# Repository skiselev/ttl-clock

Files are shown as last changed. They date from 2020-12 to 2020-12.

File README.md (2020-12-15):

# TTL Clock
74xx ICs Based Digital Clock

## Introduction
I got a bit tired from soldering SMD components, writing firmware, (and also observing people building vintage-looking Nixie clocks using modern microcontrollers). And recently when cleaning my parts boxes I found several 74LS47 7-segment decoders, some 74LS90 decade counters, and MAN1A 7-segment displays. So I thought, why not to build a nice little clock using these components.

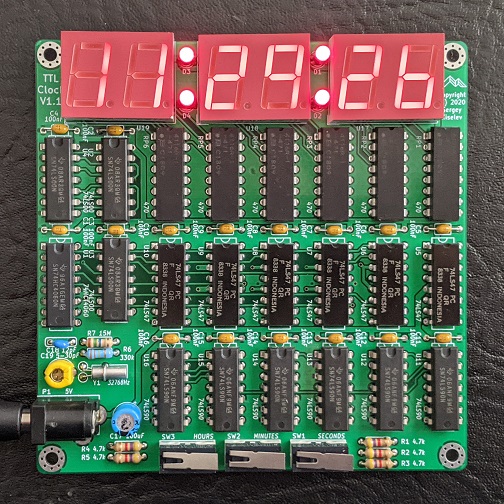
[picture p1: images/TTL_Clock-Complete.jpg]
Assembled Clock Board


## Assembly Instructions

[Assembly Instructions](Assembly_Instructions.md)

## Design Overview
Please refer to the schematic file in the Design Files section below.

The clock uses a 32768 Hz quartz crystal (X1) and 74HC4060 counter/divider IC (U1) to generate 2 Hz signal. This signal is divided further by 2 using a part of 74LS90 counter (U6). The obtained 1 Hz signal is fed to two 74LS90 counters (U11 and U12) that count seconds. The seconds reset circuit implemented using two 74LS00 NAND gates (U4A and U4B). This circuit resets both seconds and tens of seconds counters when they reach "60" or when "SECONDS" switch (SW1) is pressed, allowing seconds adjustment.

The most significant bit of tens of seconds counter is fed to the minutes counter implemented using two 74LS90 counters (U13 and U14) through a multiplexer built from three 74LS00 NAND gates (U2C, U2D, U4D). The multiplexer selects between this "one pulse per minute" signal and the 2 Hz signal allowing setting up minutes. Two additional 74LS00 NAND gates (U2A and U2B) implement an RS flip-flop used to de-bounce "MINUTES" switch (SW2). The tens of the minutes 74LS90 counter (U14) is wired so that it resets itself when it reaches count of "6", so that minutes wrap around at "60".

Similarly to minutes, the most significant bit of tens of minutes is fed to the hours counter implemented using two 74LS90 counters (U15 and U16) through a multiplexer built from three 74LS00 NAND gates (U3C, U3D, U4C). The multiplexer selects between this "one pulse per hour" signal and the 2 Hz signal allowing setting up hours. Two additional 74LS00 NAND gates (U3A and U3B) implement an RS flip-flop used to de-bounce "HOURS" switch (SW3). Both hours counters are wired in such a way that they will reset themselves once they reach the count of "24".

Six 74LS47 7-segment decoders (U5 - U10) are used to decode the binary outputs of the counters and 7-segment displays (U17 - U19) display the result in human readable 24-hours time format.

## Design Files

[Schematic - Version 1.1](KiCad/TTL_Clock-Schematic-1.1.pdf)

[Board - Version 1.1](KiCad/TTL_Clock-Board-1.1.pdf)

## Bill of Materials

[TTL Clock V1.1 project on Mouser.com](https://www.mouser.com/ProjectManager/ProjectDetail.aspx?AccessID=75baf81884) - View and order all components except of the PCB.

[TTL Clock Version 1.1 project on OSH Park](https://oshpark.com/shared_projects/GOxwvQh1) - Order PCBs.

Component type     | Reference | Description                                 | Quantity | Possible sources and notes
------------------ | --------- | ------------------------------------------- | -------- | --------------------------
PCB                |           | TTL Clock V1.1 Printed Circuit Board        | 1        | Order from [OSH Park](https://oshpark.com/shared_projects/GOxwvQh1) or another PCB manufacturer using provided KiCad or Gerber files
Stand              |           | 3D printed stand for the clock              | 1        | (Optional) Print on a 3D printer using [stand.stl](printed_parts/stand.stl). Thanks to Michael K. for designing this stand.
Screw              |           | M3 x 6mm screw                              | 2        | (Optional)
Capacitor          | C1 - C16  | 0.1uF, 50V, multilayer ceramic capacitor, axial | 16   | Mouser: [594-A104K15X7RF5UAA](https://www.mouser.com/ProductDetail/594-A104K15X7RF5UAA)
Capacitor          | C17       | 100uF, 25V, electrolytic capacitor, radial, 6.3 mm diameter | 1 | Mouser: [710-860040473003](https://www.mouser.com/ProductDetail/710-860040473003)
Capacitor          | C18       | 12pF, 50V, multilayer ceramic capacitor, 5.08 mm lead spacing | 1 | Mouser: [810-FK28C0G1H120J](https://www.mouser.com/ProductDetail/810-FK28C0G1H120J)
Trimmer Capacitor  | C19       | 5-30pF, trimmer capacitor, 5 mm lead spacing | 1       | Mouser: [659-GKG20015](https://www.mouser.com/ProductDetail/659-GKG20015)
LED                | D1 - D4   | 3 mm LED, same color as U17 - U19            | 4       | Mouser: [859-LTL-4221](https://www.mouser.com/ProductDetail/859-LTL-4221) (red, 623 nm) [859-LTL-4211](https://www.mouser.com/ProductDetail/859-LTL-4211) (red, 697 nm, 2.5 mcd), [859-LTL-4231](https://www.mouser.com/ProductDetail/859-LTL-4231) (green, 565 nm)
Connector          | P1        | DC Power Jack                               | 1        | Mouser: [806-KLDX-0202-A](https://www.mouser.com/ProductDetail/806-KLDX-0202-A)
Resistor           | R1 - R5   | 4.7 kOhm, 1/4 W                             | 5        | Mouser: [588-OK4725E-R52](https://www.mouser.com/ProductDetail/588-OK4725E-R52), [603-MFR25SFRF52-4K7](https://www.mouser.com/ProductDetail/603-MFR25SFRF52-4K7)
Resistor           | R6        | 330 kOhm, 1/4 W                             | 1        | Mouser: [588-OK3345E-R52](https://www.mouser.com/ProductDetail/588-OK3345E-R52)
Resistor           | R7        | 15 MOhm, 1/4 W                              | 1        | Mouser: [660-CF1/4C156J](https://www.mouser.com/ProductDetail/660-CF1-4C156J)
Resistor Array     | RR1 - RR6 | 470 Ohm, 8 isolated resistors, 16 pin DIP   | 6        | Mouser: [652-4116R-1LF-470](https://www.mouser.com/ProductDetail/652-4116R-1LF-470), [652-4116R-1-470](https://www.mouser.com/ProductDetail/652-4116R-1-470), or 46 x 470 ohm discrete resistors
Switch             | SW1 - SW3 | SPDT momentary switch, Omron D2F            | 3        | Mouser: [612-SS0750301F040P1A](https://www.mouser.com/ProductDetail/612-SS0750301F040P1A), [653-D2F-01L](https://www.mouser.com/ProductDetail/653-D2F-01L)
Integrated Circuit | U1        | 14-stage binary counter with oscillator, 74HC4060 | 1  | Mouser: [595-SN74HC4060N](https://www.mouser.com/ProductDetail/595-SN74HC4060N), [595-CD74HCT4060E](https://www.mouser.com/ProductDetail/595-CD74HCT4060E), [595-CD74HC4060E](https://www.mouser.com/ProductDetail/595-CD74HC4060E)
Integrated Circuit | U2 - U4   | Quad 4-input NAND gate, 74LS00              | 3        | Mouser: [595-SN74LS00N](https://www.mouser.com/ProductDetail/595-SN74LS00N), [595-SN74LS00NE4](https://www.mouser.com/ProductDetail/595-SN74LS00NE4)
Integrated Circuit | U5 - U10  | BCD to 7-segment decoder, 74LS47 or 74LS247 | 6        | Mouser: [595-SN74LS47N](https://www.mouser.com/ProductDetail/595-SN74LS47N), [595-SN74LS47NE4](https://www.mouser.com/ProductDetail/SN74LS47NE4), [595-SN74LS247N](https://www.mouser.com/ProductDetail/595-SN74LS247N), [595-SN74LS247NE4](https://www.mouser.com/ProductDetail/595-SN74LS247NE4)
Integrated Circuit | U11 - U16 | Decade counter, 74LS90                      | 6        | Mouser: [595-SN74LS90N](https://www.mouser.com/ProductDetail/595-SN74LS90N), [595-SN74LS90NE4](https://www.mouser.com/ProductDetail/595-SN74LS90NE4)
LED Display        | U17 - U19 | 7-segment LED display, 2 digits, common anode | 3      | Mouser: [859-LTD-6910HR](https://www.mouser.com/ProductDetail/859-LTD-6910HR) (red, 623 nm), [859-LTD-6410G](https://www.mouser.com/ProductDetail/859-LTD-6410G) (green, 569 nm)
Crystal Resonator  | X1        | 32768 Hz, 12.5pF load capacitance, tuning fork | 1     | Mouser: [695-CFS-20632768EZBB](https://www.mouser.com/ProductDetail/695-CFS-20632768EZBB), [815-AB26T-32.768KHZ](https://www.mouser.com/ProductDetail/815-AB26T-32.768KHZ)
Power Supply       |           | 5 V, 550 mA                                 | 1        | Mouser: [490-SWI3-5-N-P5](https://www.mouser.com/ProductDetail/490-SWI3-5-N-P5) (US plug), [490-SWI3-5-E-P5](https://www.mouser.com/ProductDetail/490-SWI3-5-E-P5) (EU plug)

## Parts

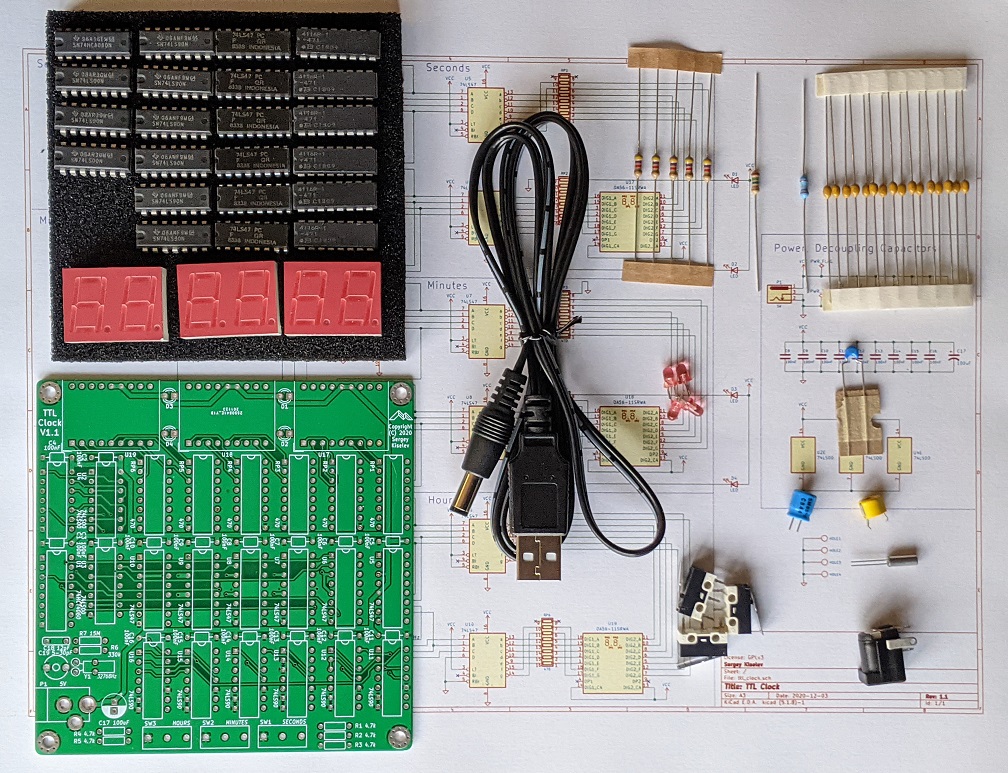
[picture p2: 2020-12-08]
images/TTL_Clock-Kit_Parts_Large.jpg

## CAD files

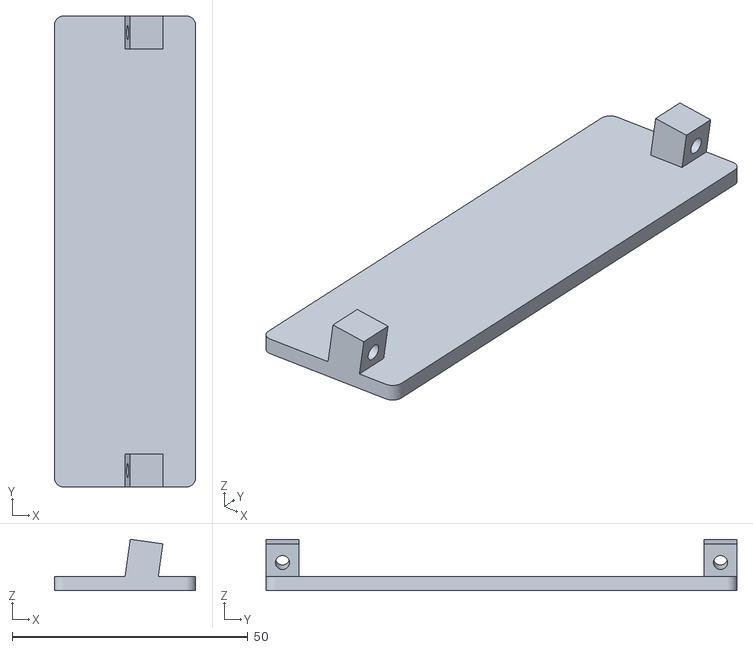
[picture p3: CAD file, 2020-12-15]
printed_parts/stand.stl
30.0 x 100.0 x 10.9

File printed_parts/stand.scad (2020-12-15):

// TTL Clock Stand
//
// This program is free software: you can redistribute it and/or modify
// it under the terms of the GNU General Public License as published by
// the Free Software Foundation, either version 3 of the License, or
// (at your option) any later version.
//
// This program is distributed in the hope that it will be useful,
// but WITHOUT ANY WARRANTY; without even the implied warranty of
// MERCHANTABILITY or FITNESS FOR A PARTICULAR PURPOSE.  See the
// GNU General Public License for more details.
//
// You should have received a copy of the GNU General Public License
// along with this program.  If not, see <https://www.gnu.org/licenses/>.

corner_radius = 2;
$fn = 60;
width=100;
depth=30;
thick=3;
standoff_width=7;
standoff_depth=7;
standoff_height=8;
standoff_angle=8;
hole_diameter=3;

render_stand();

module render_stand() {
    // base plate
    rounded_box(depth,width,thick);
    // standoff 1
    translate([depth/2,0,thick]) {
        standoff(standoff_depth,standoff_width,standoff_height,hole_diameter,standoff_angle);
    }
    // standoff 2
    translate([depth/2,width-standoff_width,thick]) {
        standoff(standoff_depth,standoff_width,standoff_height,hole_diameter,standoff_angle);
    }
}

////////////////////////////////////////////////////////////////////////////////
module standoff(d,w,h,hole,angle)
{
    rotate([0,angle,0]) {
        difference () {
            cube([d,w,h]);
            translate([d/2,w/2,h/2]) {
                rotate([0,90,0]) {
                    cylinder(d=hole,h=d+0.2,center=true);
                }
            }
        }
    }
}

////////////////////////////////////////////////////////////////////////////////
// Rounded Box
module rounded_box(w,l,h,cr=corner_radius)
{
    translate([cr,cr,0]) {
        minkowski() {
            cube([w-cr*2,l-cr*2,h/2]);
            cylinder(r=cr,h=h/2,center=false);
        }
    }
}

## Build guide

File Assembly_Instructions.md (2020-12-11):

# TTL Clock - Assembly Instructions

## Introduction
TTL Clock is a medium complexity project. While it uses through-hole components only, and therefore requires only basic soldering skills, it contains quite a few components.

## Prerequisites

### Tools and Supplies

* Soldering iron or soldering station
* Needle nose pliers
* Cutters
* Well lit and ventilated workspace
* Solder
* Small Phillips screwdriver (optional)
* Multimeter (optional)
* ESD safe surface and ESD strap (optional)
* Isopropyl alcohol and a wipe to clean the flux (optional)

### Parts

* TTL Clock parts as described in [Bill of Materials](https://github.com/skiselev/ttl-clock#bill-of-materials)
* USB power supply, or 5V DC power supply with 2.1 mm internal diameter / 5.5 mm external diameter plug

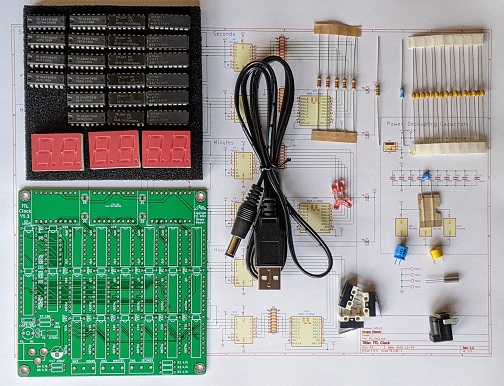
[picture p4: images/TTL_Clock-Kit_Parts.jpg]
TTL Clock kit parts


## Assembly Steps

1. Gather supplies and parts
  * Check that you have all the equipment and parts listed in the [Prerequisites](prerequisites) section above
  * Organize your workspace. If available, use ESD-safe surface and ESD strap when working on this project
2. Assemble the components going from lower profile components to higher profile components. Here is the recommended order:
  * Form the leads of 100 nF capacitors as shown on the photo below. Using needle nose pliers, hold the capacitor by the lead close to the capacitor's package, and then bend the lead using your fingers. The distance between bent leads should be 7.62 mm (0.3")

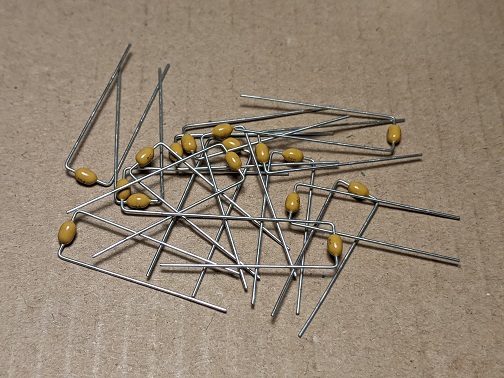
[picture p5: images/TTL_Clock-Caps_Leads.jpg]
Formed capacitor leads

  * Solder capacitors C1 - C16. Note that these are non-polarized ceramic capacitors, so they can be oriented either way. Trim the leads using cutters

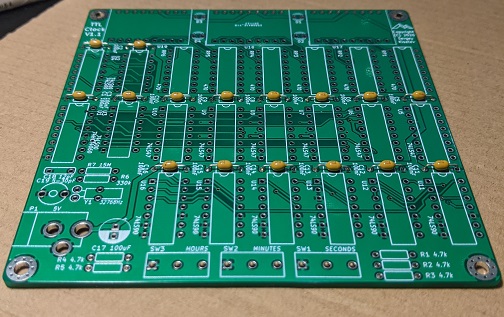
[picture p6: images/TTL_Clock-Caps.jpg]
Board with soldered capacitors

  * Form the leads of the resistors. Using your fingers bend the leads down as close to the resistor's package as possible. The distance between bent leads should be 7.62 mm (0.3")

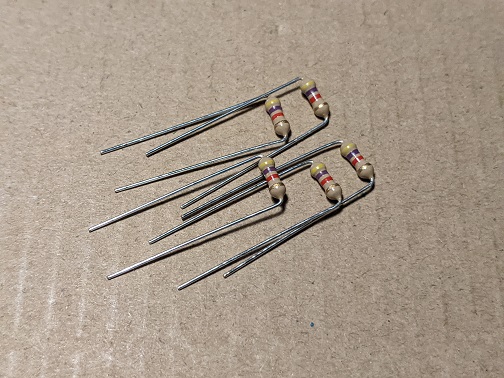
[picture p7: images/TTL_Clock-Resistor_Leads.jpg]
Formed resistor leads

  * Solder 4.7 kohm resistors R1 - R5. These resistors are marked with yellow-purple-red-gold color code. The resistors are not polarized and can be oriented either way. Trim the leads using cutters
  * Solder 330 kohm resistor R6. This resistor is marked with orange-orange-yellow-gold color code. Trim the leads using cutters
  * Solder 15 Mohm resistor R7. This resistor is marked with brown-green-blue-golden color code. Trim the leads using cutters

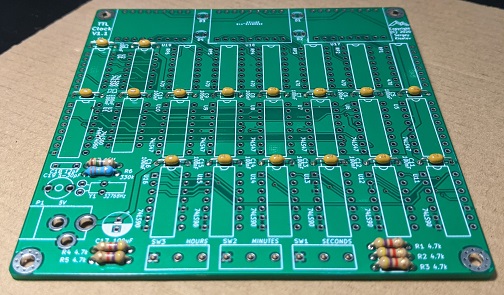
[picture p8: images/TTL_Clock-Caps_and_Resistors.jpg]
Board with soldered resistors and capacitors

  * Form the leads of the crystal oscillator X1. Hold it by the leads with needle nose pliers as close to the package as possible, when gently bend the leads down
  * Solder crystal oscillator. Trim the leads using cutters
  * Using one of the cut resistor leads and needle nose pliers, form a U-shaped bracket to hold the crystal oscillator as shown on the photo below

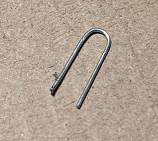
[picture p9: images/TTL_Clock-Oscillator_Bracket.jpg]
Oscillator bracket

  * Solder the crystal oscillator bracket. Make sure that it securely holds the crystal oscillator

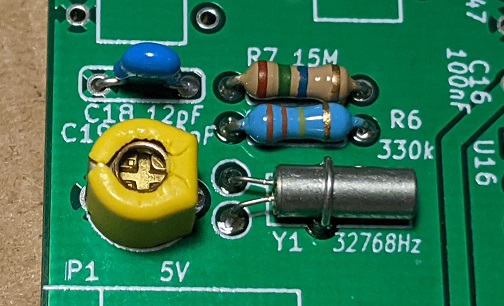
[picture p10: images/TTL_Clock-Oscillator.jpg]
Oscillator area

  * Solder U1 - U16 integrated circuits as follows:
    * Prior to placing an integrated circuit on the board, bend its leads slightly, so they point 90 degrees downward. Put the IC on the side and gently push it down to bend the leads. Repeat on the other side of the IC
    * Double check that you're placing the integrated circuit in the right spot on the board, check the IC orientation. The index notch on the IC should match the boards silkscreen
    * Solder two opposite pins (for example, pin 1 and pin 9). Flip the board to the component side and __check the IC orientation and position again!__ It is not too late to desolder the IC and fix the mistake.
    * Solder remaining pins quickly (3 seconds per pin), to avoid overheating the integrated circuit
  * Solder RR1 - RR6 resistor arrays. Follow integrated circuits instructions in the previous step
  * Solder C18 capacitor. This is a non-polarized ceramic capacitor, so it can be oriented either way
  * Solder C19 trimmer capacitor. This is a non-polarized capacitor, so it can be oriented either way

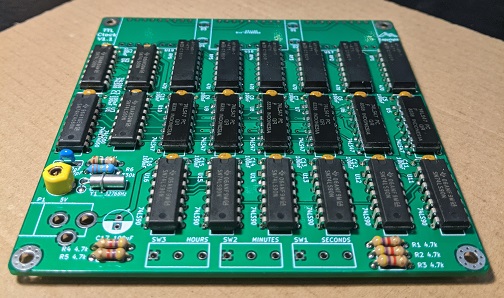
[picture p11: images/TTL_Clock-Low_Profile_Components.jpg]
Board with low profile components

  * Solder C17 capacitor. Note that this is a __polarized__ electrolytic capacitor and it needs to be oriented properly. Make sure that the negative lead of the capacitor (marked on the package) matches the white colored area on the PCB.
  * Solder LEDs D1 - D4
    * Note that the LEDs are __polarized__. The square pads on the board correspond to the negative (cathode) lead of the LED. The negative leads on the LED usually marked by an indent on otherwise round LED package, or by a shorter lead. The LEDs included in the kit will have their positive leads colored red. If in doubt - use the multimeter (set to diode mode) to check the polarity
    * When soldering LEDs, it is recommended to leave some space between the LED packages and the board and to keep soldering time to minimal to avoid overheating the LED
  * Solder LED displays U17 - U19
    * LED displays are __polarized__. Make sure that they are oriented correctly prior to soldering. The proper orientation can be easily determined by looking at the decimal point on the displays. It should reside on the bottom side on the display (close to the resistor arrays)
    * As with LEDs and integrated circuits, avoid overheating the displays
  * Solder DC power jack P1 
  * Solder SW1 - SW3 switches. Note that switches should be __oriented__ so that the pin 1 is on the left side. Pin 1 is the pin closest to the place where the hinge attaches to the switch. Refer to the picture below
 
Complete board

3. Double check your work. Make sure that all components and all leads are well soldered
4. If desired, clean the flux residue using wipes or q-tips soaked in isopropyl alcohol. Let the board dry before testing
5. Power on the board. It should work right away!
6. Set the time using the buttons
  * Reset seconds first
  * Set minutes next
  * Finally set hours
7. If needed fine tune the clock by turning the trim capacitor using a smallscrew driver. You might want to let the clock run overnight to check if gains or loses time

__Congratulations! Enjoy your TTL Clock!__

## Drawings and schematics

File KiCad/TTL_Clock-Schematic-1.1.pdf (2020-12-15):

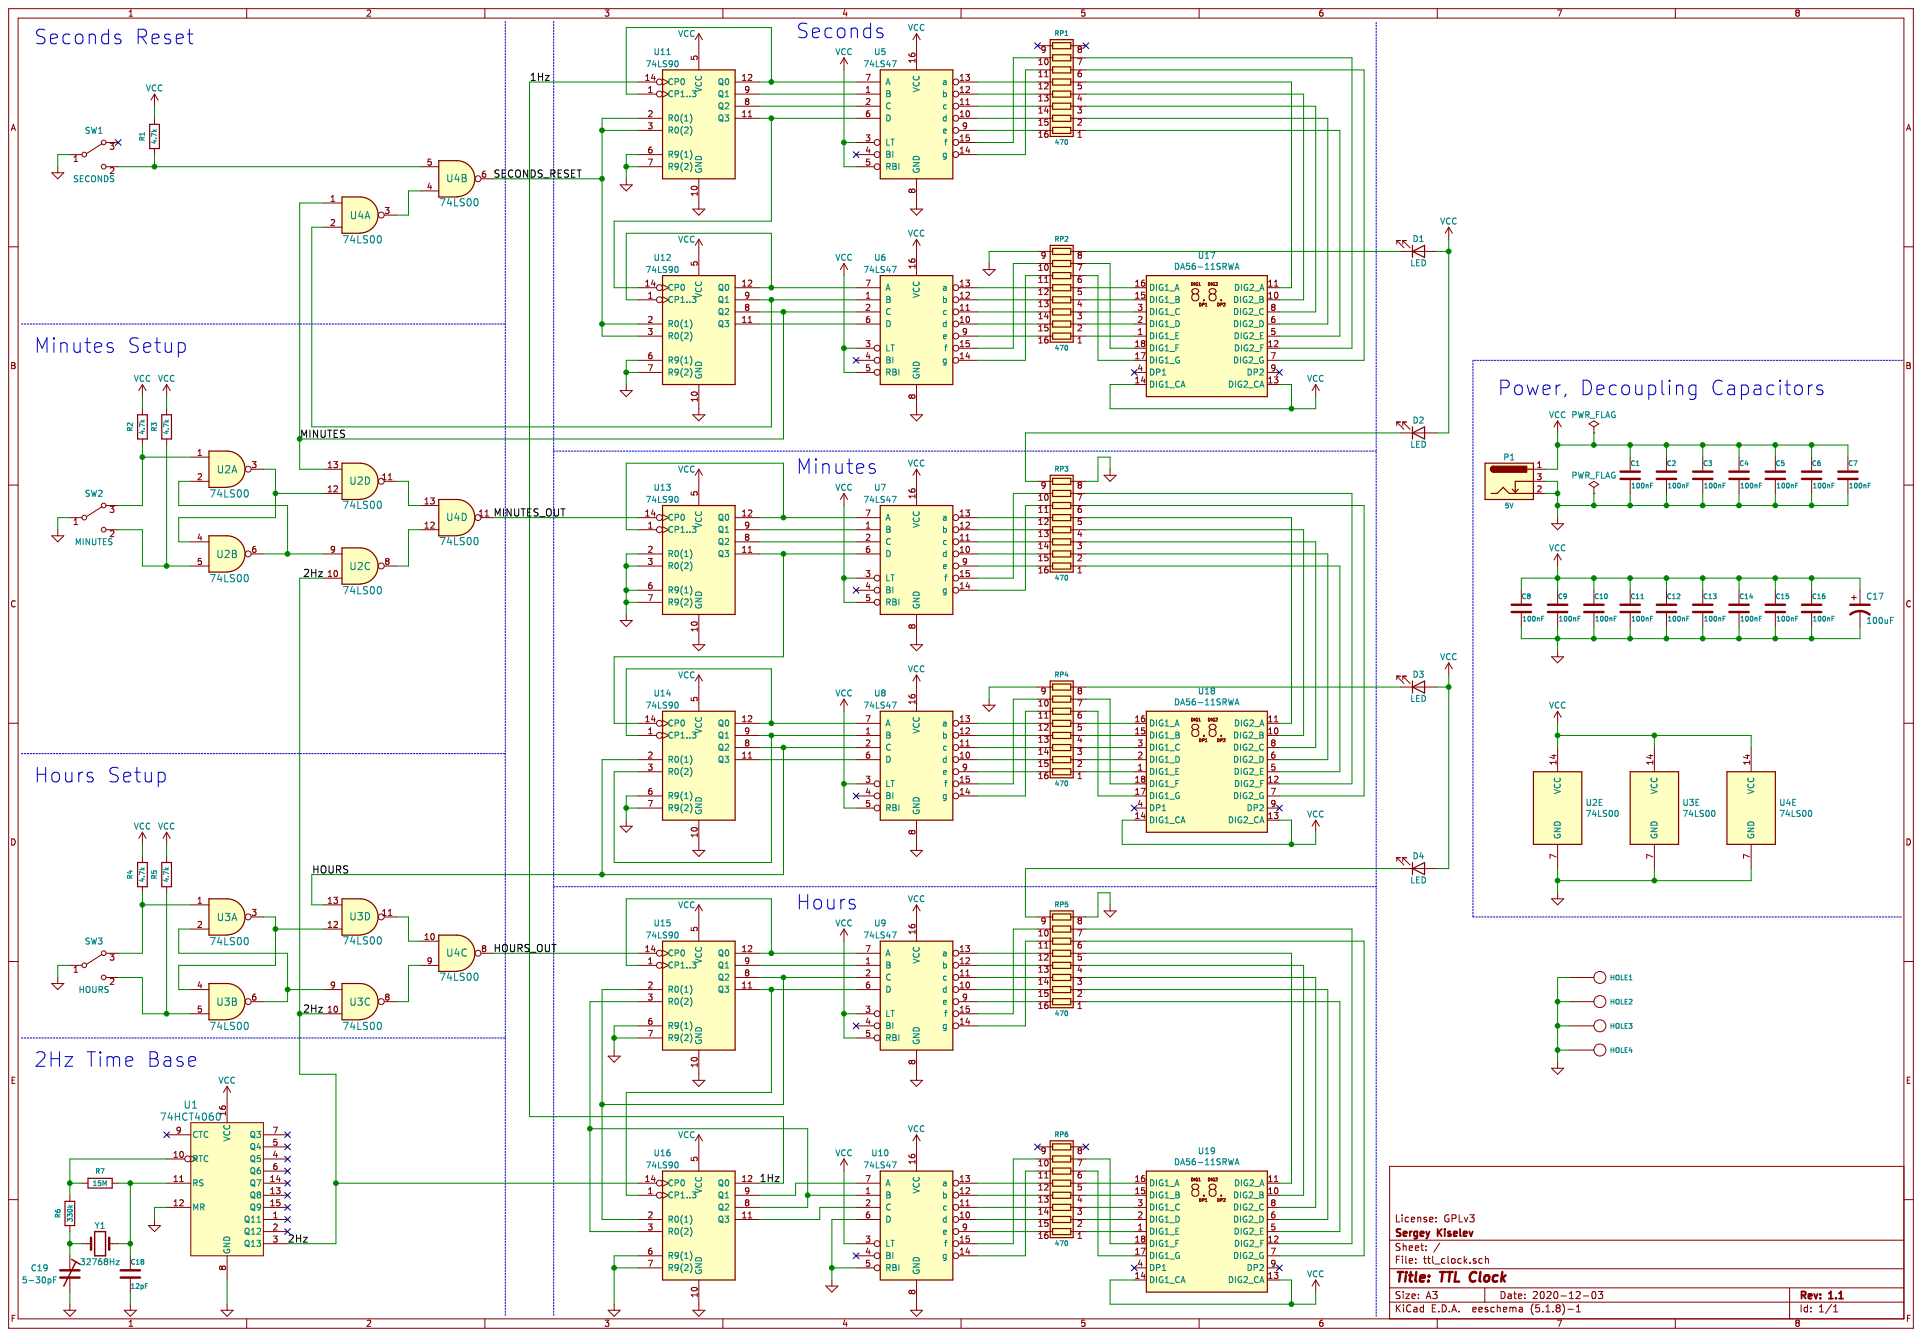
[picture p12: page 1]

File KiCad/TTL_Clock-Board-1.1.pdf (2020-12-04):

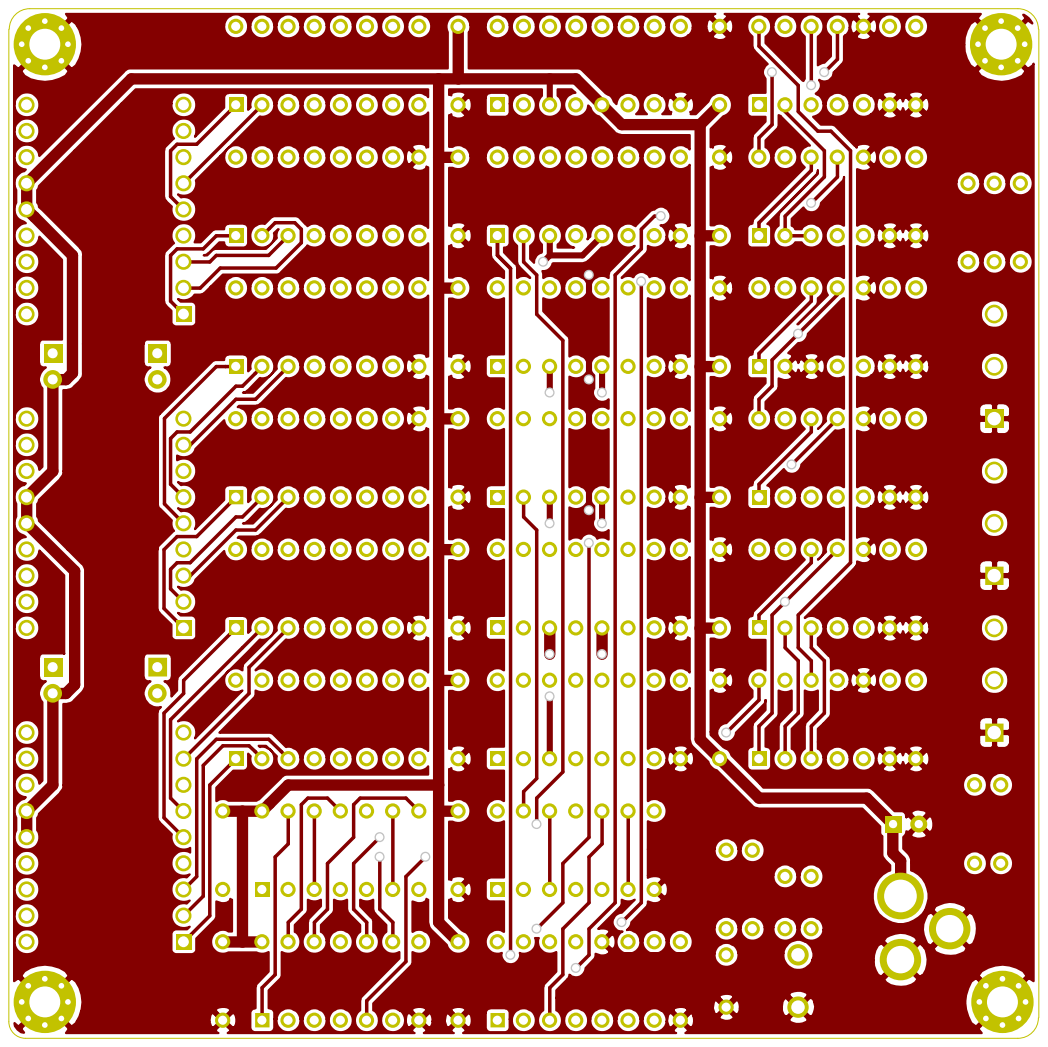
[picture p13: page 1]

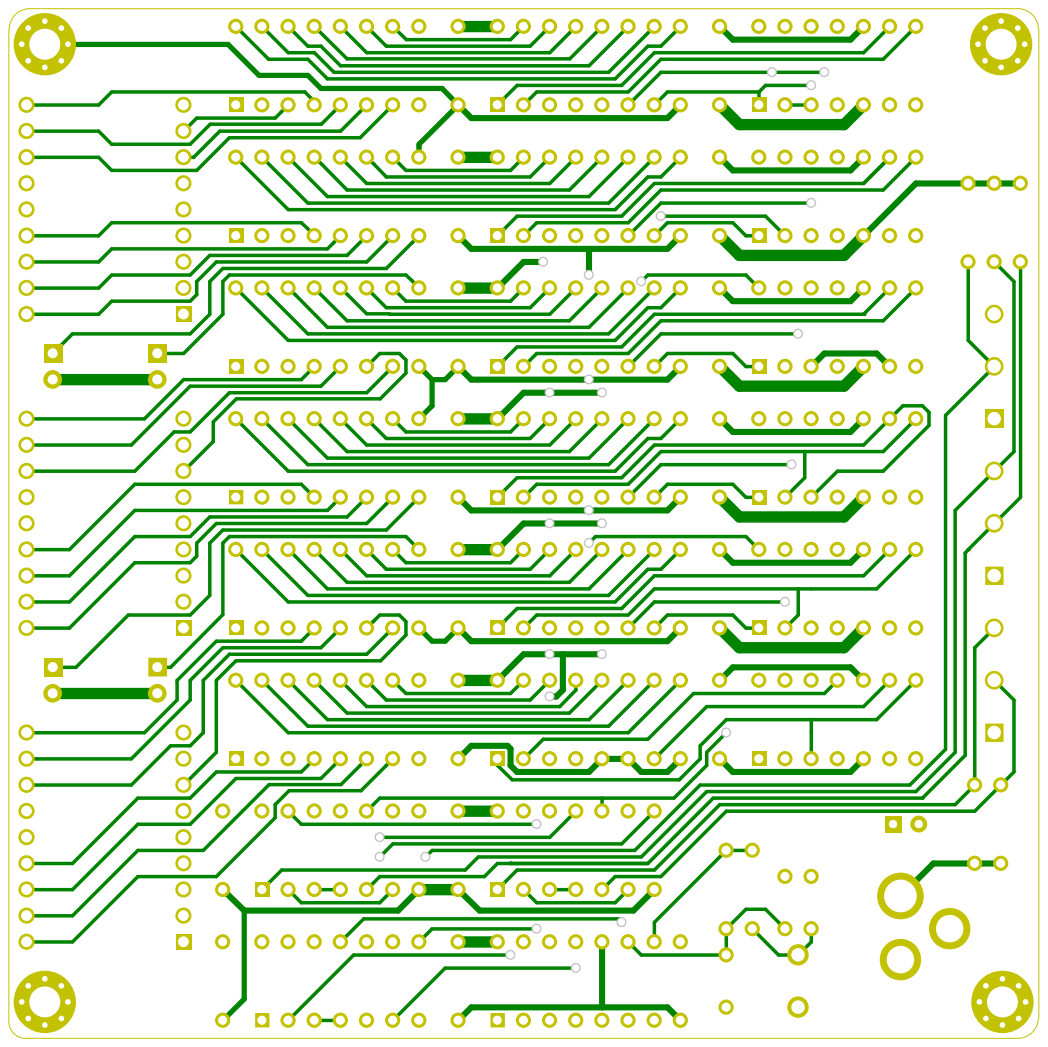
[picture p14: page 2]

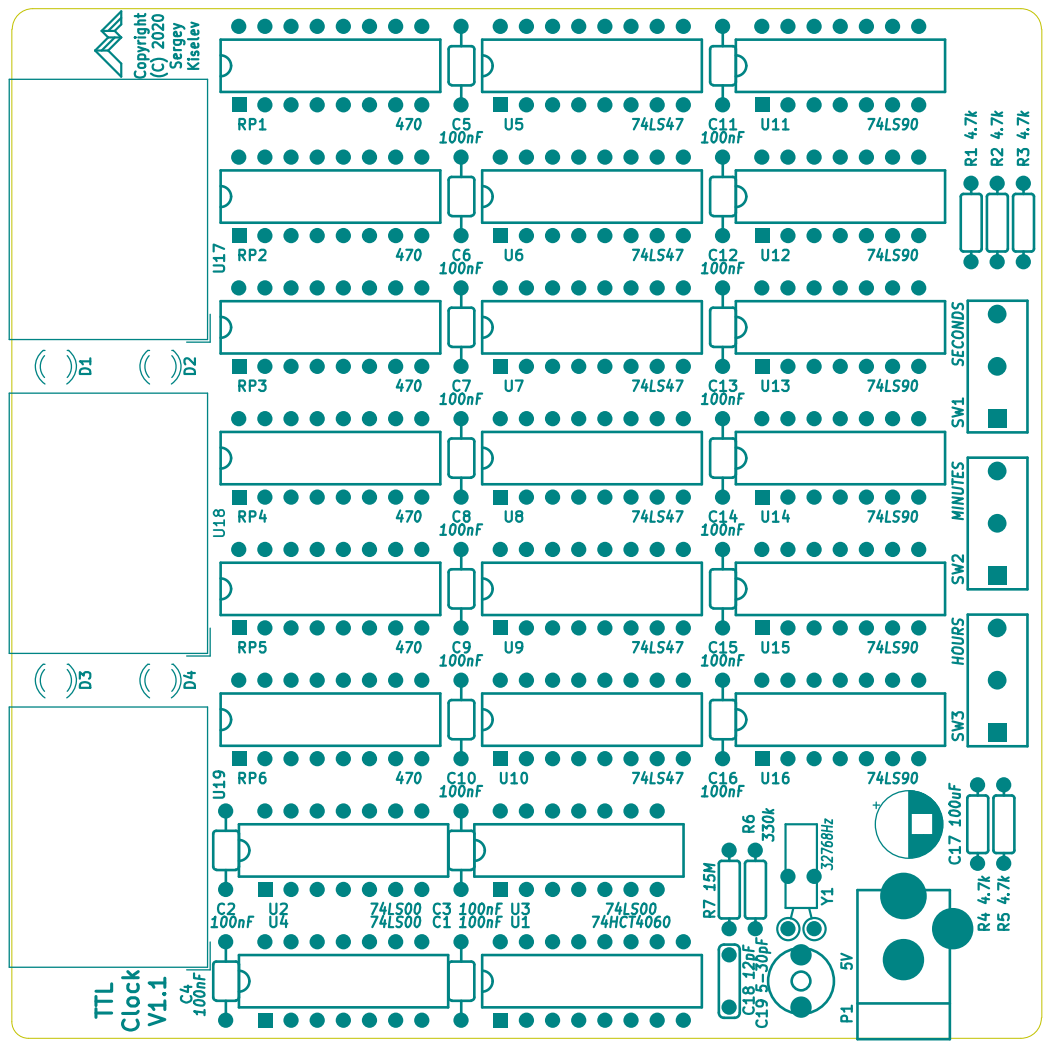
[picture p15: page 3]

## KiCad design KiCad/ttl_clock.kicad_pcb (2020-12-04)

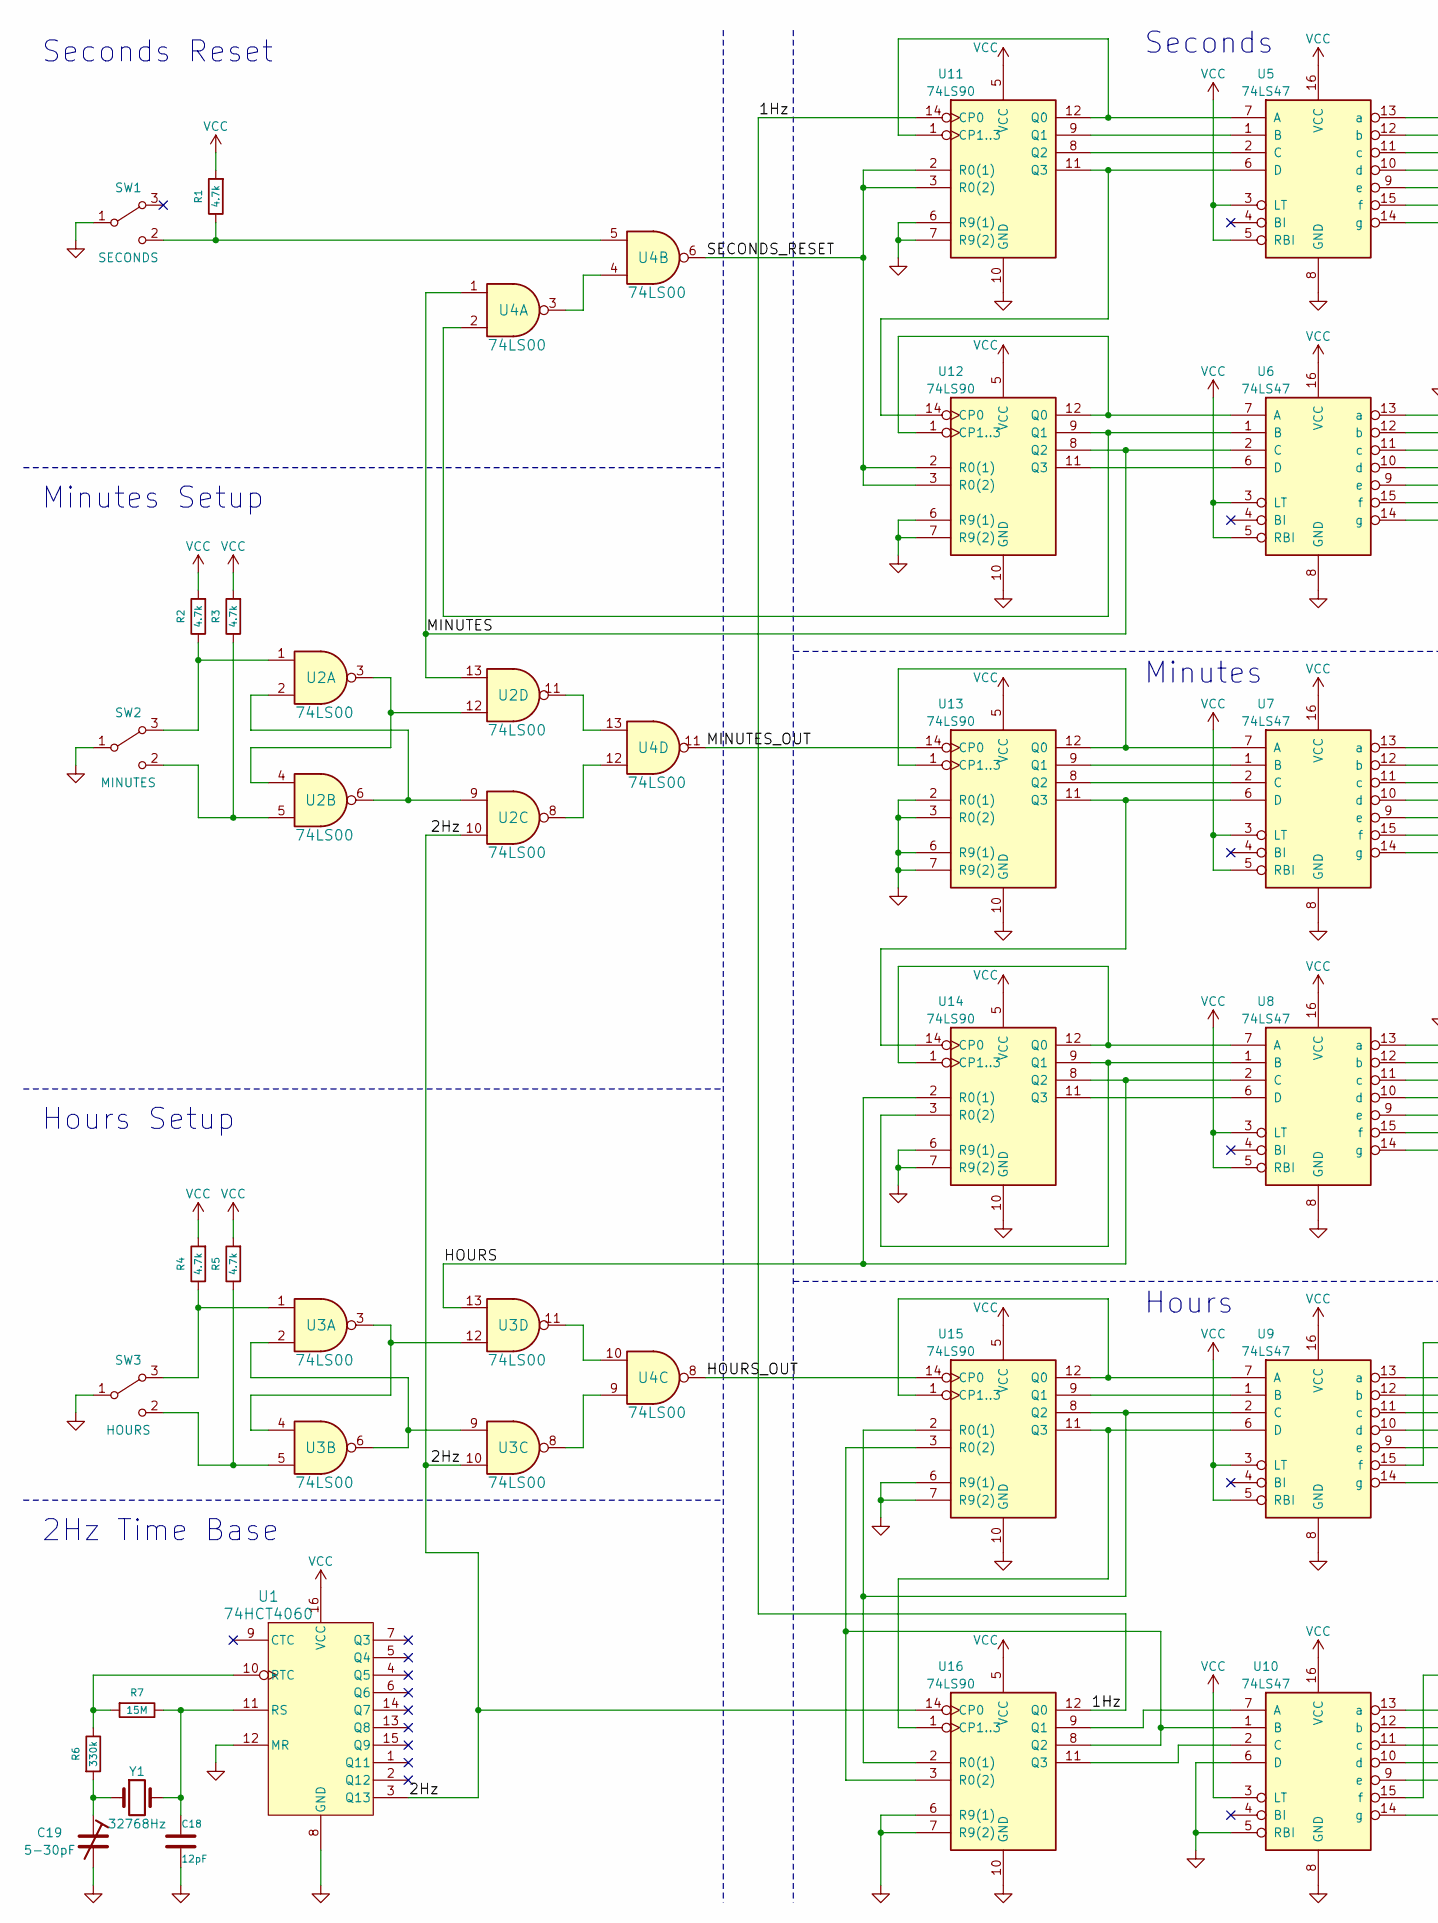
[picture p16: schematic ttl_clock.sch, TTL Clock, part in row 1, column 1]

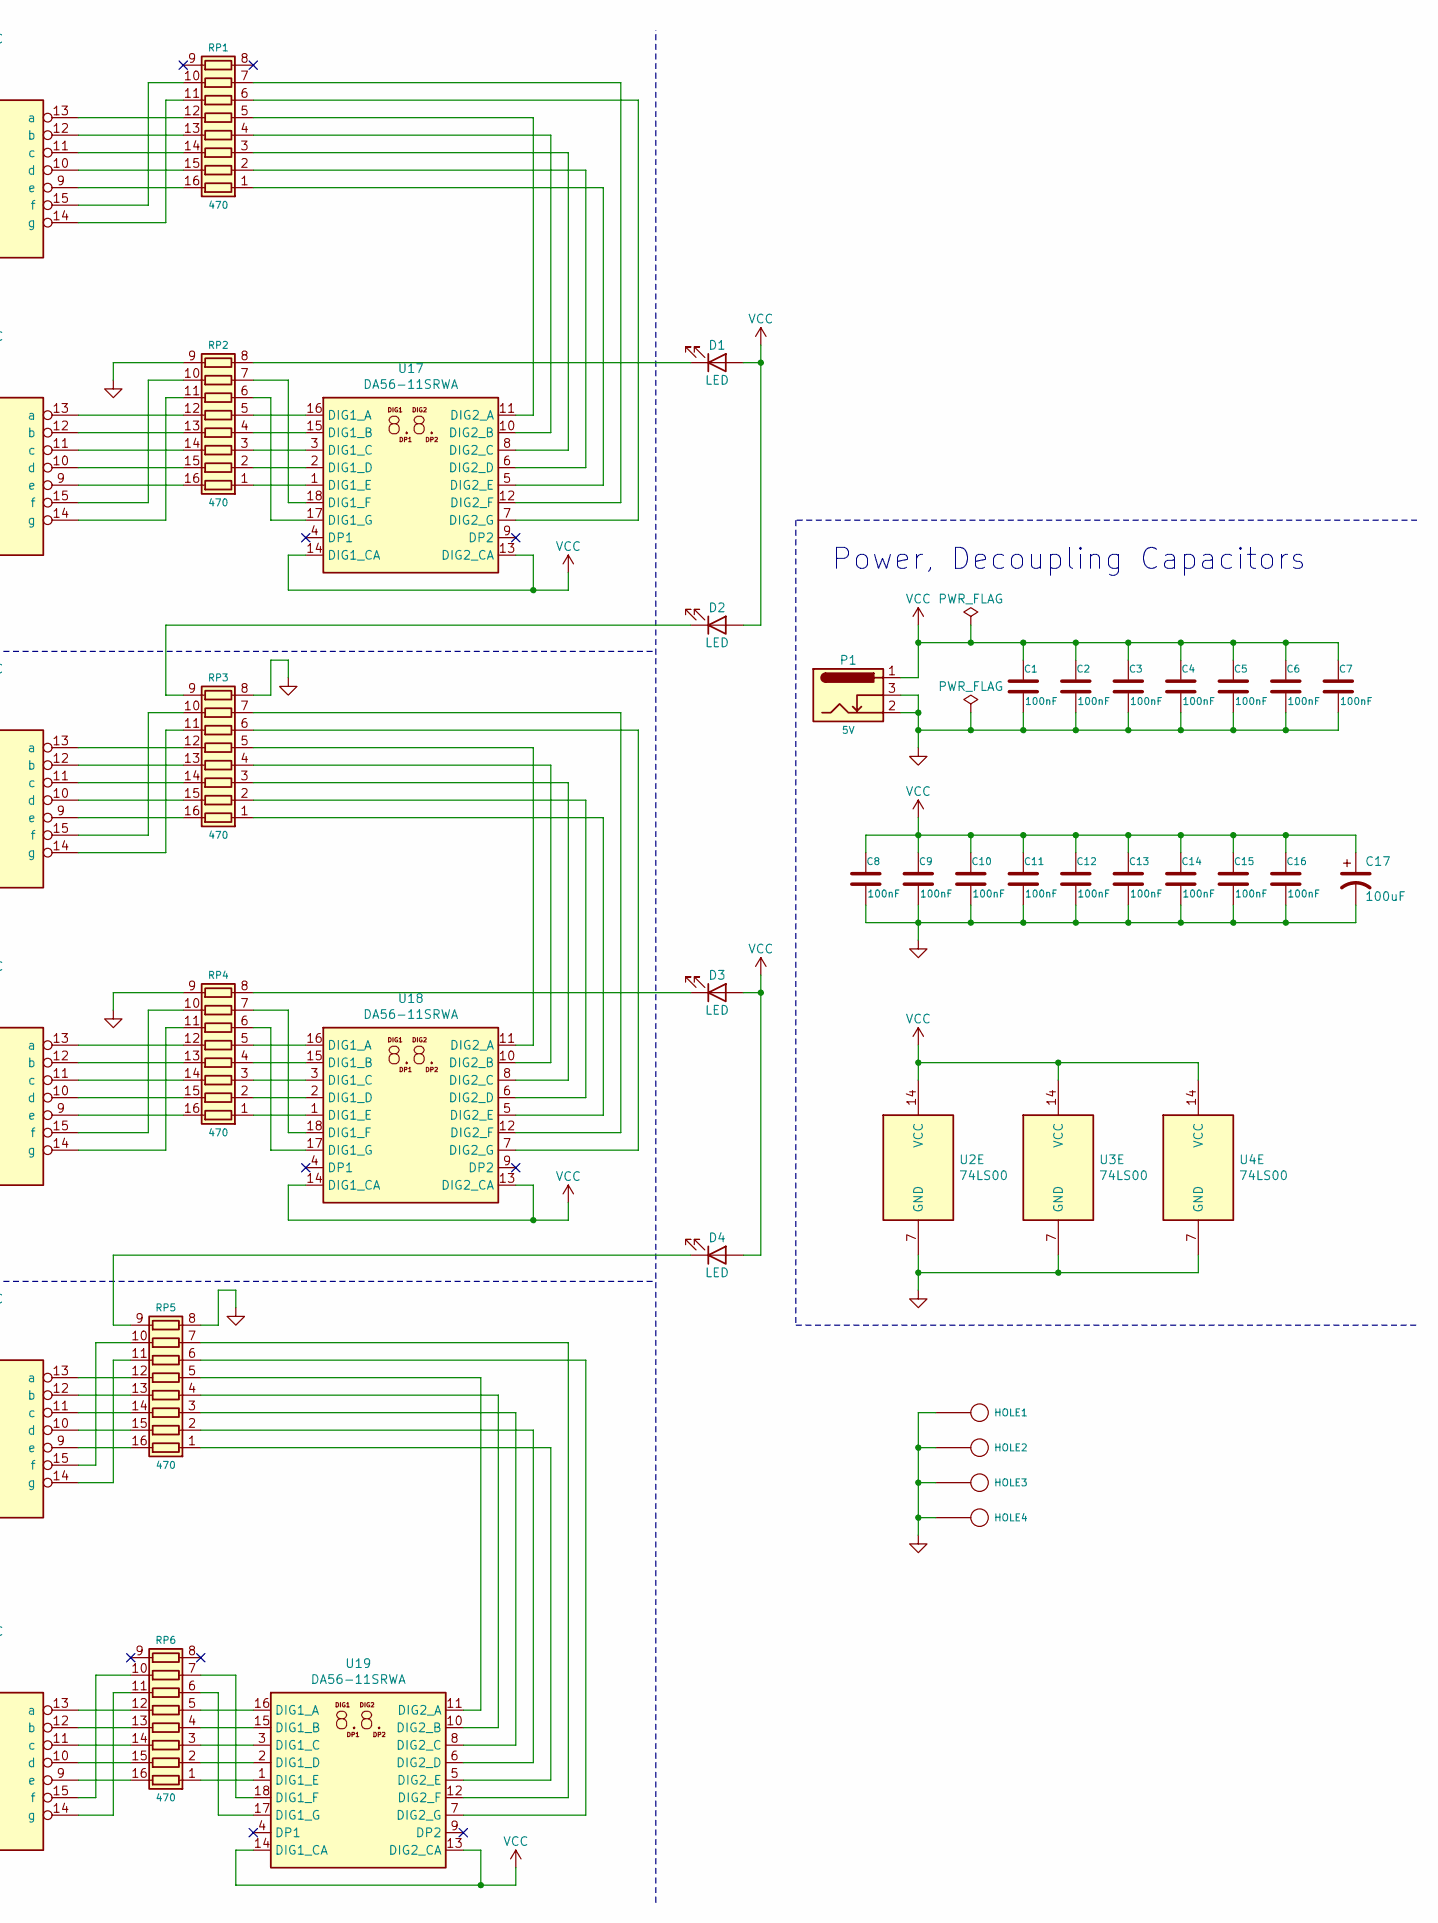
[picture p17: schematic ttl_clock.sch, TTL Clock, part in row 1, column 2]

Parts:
C1, C2, C3, C4, C5, C6, C7, C8, C9, C10, C11, C12, C13, C14, C15, C16: 100nF; Cap_Cer_762
C17: 100uF; CP_Radial_D6.3mm_P2.50mm
C18: 12pF; Cap_Cer_508
C19: 5-30pF; C_Trim_Murata
D1, D2, D3, D4: LED; LED_D3.0mm_FlatTop
HOLE1, HOLE2, HOLE3, HOLE4: CONN_1; MountingHole_3mm_Pad_Via
P1: 5V; Conn_Power_Jack_Circular_Pads
R1, R2, R3, R4, R5: 4.7k; Res_762
R6: 330k; Res_762
R7: 15M; Res_762
RP1, RP2, RP3, RP4, RP5, RP6: 470; IC_DIP16_300
SW1: SECONDS; Switch_SPDP_D2F
SW2: MINUTES; Switch_SPDP_D2F
SW3: HOURS; Switch_SPDP_D2F
U1: 74HCT4060; IC_DIP16_300
U2, U3, U4: 74LS00; IC_DIP14_300
U5, U6, U7, U8, U9, U10: 74LS47; IC_DIP16_300
U11, U12, U13, U14, U15, U16: 74LS90; IC_DIP14_300
U17, U18, U19: DA56-11SRWA; DA56-11SURKWA
Y1: 32768Hz; Crystal_32K_Horiz

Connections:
/1Hz: U11.14 (CP0), U16.12 (Q0)
/2Hz: U1.3 (Q13), U2.10, U3.10, U16.14 (CP0)
/HOURS: U3.13, U8.2 (C), U14.2 (R0(1)), U14.8 (Q2)
/HOURS_OUT: U4.8, U15.14 (CP0)
/MINUTES: U2.13, U4.1, U6.2 (C), U12.8 (Q2)
/MINUTES_OUT: U4.11, U13.14 (CP0)
/SECONDS_RESET: U4.6, U11.2 (R0(1)), U11.3 (R0(2)), U12.2 (R0(1)), U12.3 (R0(2))
GND: C1.2, C2.2, C3.2, C4.2, C5.2, C6.2, C7.2, C8.2, C9.2, C10.2, C11.2, C12.2, C13.2, C14.2, C15.2, C16.2, C17.2, C18.2, C19.2, HOLE1.1, HOLE2.1, HOLE3.1, HOLE4.1, P1.2, P1.3, RP2.9 (R8.2), RP3.8 (R8.1), RP4.9 (R8.2), RP5.8 (R8.1), SW1.1 (B), SW2.1 (B), SW3.1 (B), U1.8 (GND), U1.12 (MR), U2.7 (GND), U3.7 (GND), U4.7 (GND), U5.8 (GND), U6.8 (GND), U7.8 (GND), U8.8 (GND), U9.8 (GND), U10.5 (RBI), U10.6 (D), U10.8 (GND), U11.6 (R9(1)), U11.7 (R9(2)), U11.10 (GND), U12.6 (R9(1)), U12.7 (R9(2)), U12.10 (GND), U13.2 (R0(1)), U13.3 (R0(2)), U13.6 (R9(1)), U13.7 (R9(2)), U13.10 (GND), U14.6 (R9(1)), U14.7 (R9(2)), U14.10 (GND), U15.6 (R9(1)), U15.7 (R9(2)), U15.10 (GND), U16.6 (R9(1)), U16.7 (R9(2)), U16.10 (GND)
unnamed: C18.1, R7.1, U1.11 (RS), Y1.2
unnamed: C19.1, R6.2, Y1.1
unnamed: D1.1 (K), RP2.8 (R8.1)
unnamed: D2.1 (K), RP3.9 (R8.2)
unnamed: D3.1 (K), RP4.8 (R8.1)
unnamed: D4.1 (K), RP5.9 (R8.2)
unnamed: R1.1, SW1.2 (C), U4.5
unnamed: R2.1, SW2.3 (A), U2.1
unnamed: R3.1, SW2.2 (C), U2.5
unnamed: R4.1, SW3.3 (A), U3.1
unnamed: R5.1, SW3.2 (C), U3.5
unnamed: R6.1, R7.2, U1.10 (RTC)
unnamed: RP1.1 (R1.1), U17.5 (DIG2_E)
unnamed: RP1.2 (R2.1), U17.6 (DIG2_D)
unnamed: RP1.3 (R3.1), U17.8 (DIG2_C)
unnamed: RP1.4 (R4.1), U17.10 (DIG2_B)
unnamed: RP1.5 (R5.1), U17.11 (DIG2_A)
unnamed: RP1.6 (R6.1), U17.7 (DIG2_G)
unnamed: RP1.7 (R7.1), U17.12 (DIG2_F)
unnamed: RP1.10 (R7.2), U5.15 (f)
unnamed: RP1.11 (R6.2), U5.14 (g)
unnamed: RP1.12 (R5.2), U5.13 (a)
unnamed: RP1.13 (R4.2), U5.12 (b)
unnamed: RP1.14 (R3.2), U5.11 (c)
unnamed: RP1.15 (R2.2), U5.10 (d)
unnamed: RP1.16 (R1.2), U5.9 (e)
unnamed: RP2.1 (R1.1), U17.1 (DIG1_E)
unnamed: RP2.2 (R2.1), U17.2 (DIG1_D)
unnamed: RP2.3 (R3.1), U17.3 (DIG1_C)
unnamed: RP2.4 (R4.1), U17.15 (DIG1_B)
unnamed: RP2.5 (R5.1), U17.16 (DIG1_A)
unnamed: RP2.6 (R6.1), U17.17 (DIG1_G)
unnamed: RP2.7 (R7.1), U17.18 (DIG1_F)
unnamed: RP2.10 (R7.2), U6.15 (f)
unnamed: RP2.11 (R6.2), U6.14 (g)
unnamed: RP2.12 (R5.2), U6.13 (a)
unnamed: RP2.13 (R4.2), U6.12 (b)
unnamed: RP2.14 (R3.2), U6.11 (c)
unnamed: RP2.15 (R2.2), U6.10 (d)
unnamed: RP2.16 (R1.2), U6.9 (e)
unnamed: RP3.1 (R1.1), U18.5 (DIG2_E)
unnamed: RP3.2 (R2.1), U18.6 (DIG2_D)
unnamed: RP3.3 (R3.1), U18.8 (DIG2_C)
unnamed: RP3.4 (R4.1), U18.10 (DIG2_B)
unnamed: RP3.5 (R5.1), U18.11 (DIG2_A)
unnamed: RP3.6 (R6.1), U18.7 (DIG2_G)
unnamed: RP3.7 (R7.1), U18.12 (DIG2_F)
unnamed: RP3.10 (R7.2), U7.15 (f)
unnamed: RP3.11 (R6.2), U7.14 (g)
unnamed: RP3.12 (R5.2), U7.13 (a)
unnamed: RP3.13 (R4.2), U7.12 (b)
unnamed: RP3.14 (R3.2), U7.11 (c)
unnamed: RP3.15 (R2.2), U7.10 (d)
unnamed: RP3.16 (R1.2), U7.9 (e)
unnamed: RP4.1 (R1.1), U18.1 (DIG1_E)
unnamed: RP4.2 (R2.1), U18.2 (DIG1_D)
unnamed: RP4.3 (R3.1), U18.3 (DIG1_C)
unnamed: RP4.4 (R4.1), U18.15 (DIG1_B)
unnamed: RP4.5 (R5.1), U18.16 (DIG1_A)
unnamed: RP4.6 (R6.1), U18.17 (DIG1_G)
unnamed: RP4.7 (R7.1), U18.18 (DIG1_F)
unnamed: RP4.10 (R7.2), U8.15 (f)
unnamed: RP4.11 (R6.2), U8.14 (g)
unnamed: RP4.12 (R5.2), U8.13 (a)
unnamed: RP4.13 (R4.2), U8.12 (b)
unnamed: RP4.14 (R3.2), U8.11 (c)
unnamed: RP4.15 (R2.2), U8.10 (d)
unnamed: RP4.16 (R1.2), U8.9 (e)
unnamed: RP5.1 (R1.1), U19.5 (DIG2_E)
unnamed: RP5.2 (R2.1), U19.6 (DIG2_D)
unnamed: RP5.3 (R3.1), U19.8 (DIG2_C)
unnamed: RP5.4 (R4.1), U19.10 (DIG2_B)
unnamed: RP5.5 (R5.1), U19.11 (DIG2_A)
unnamed: RP5.6 (R6.1), U19.7 (DIG2_G)
unnamed: RP5.7 (R7.1), U19.12 (DIG2_F)
unnamed: RP5.10 (R7.2), U9.15 (f)
unnamed: RP5.11 (R6.2), U9.14 (g)
unnamed: RP5.12 (R5.2), U9.13 (a)
unnamed: RP5.13 (R4.2), U9.12 (b)
unnamed: RP5.14 (R3.2), U9.11 (c)
unnamed: RP5.15 (R2.2), U9.10 (d)
unnamed: RP5.16 (R1.2), U9.9 (e)
unnamed: RP6.1 (R1.1), U19.1 (DIG1_E)
unnamed: RP6.2 (R2.1), U19.2 (DIG1_D)
unnamed: RP6.3 (R3.1), U19.3 (DIG1_C)
unnamed: RP6.4 (R4.1), U19.15 (DIG1_B)
unnamed: RP6.5 (R5.1), U19.16 (DIG1_A)
unnamed: RP6.6 (R6.1), U19.17 (DIG1_G)
unnamed: RP6.7 (R7.1), U19.18 (DIG1_F)
unnamed: RP6.10 (R7.2), U10.15 (f)
unnamed: RP6.11 (R6.2), U10.14 (g)
unnamed: RP6.12 (R5.2), U10.13 (a)
unnamed: RP6.13 (R4.2), U10.12 (b)
unnamed: RP6.14 (R3.2), U10.11 (c)
unnamed: RP6.15 (R2.2), U10.10 (d)
unnamed: RP6.16 (R1.2), U10.9 (e)
unnamed: U2.2, U2.6, U2.9
unnamed: U2.8, U4.12
unnamed: U2.11, U4.13
unnamed: U2.3, U2.4, U2.12
unnamed: U3.2, U3.6, U3.9
unnamed: U3.8, U4.9
unnamed: U3.11, U4.10
unnamed: U3.3, U3.4, U3.12
unnamed: U4.3, U4.4
unnamed: U10.1 (B), U15.3 (R0(2)), U16.3 (R0(2)), U16.8 (Q2)
unnamed: U10.2 (C), U16.11 (Q3)
unnamed: U10.7 (A), U16.9 (Q1)
unnamed: U5.7 (A), U11.1 (CP1..3), U11.12 (Q0)
unnamed: U5.2 (C), U11.8 (Q2)
unnamed: U5.1 (B), U11.9 (Q1)
unnamed: U5.6 (D), U11.11 (Q3), U12.14 (CP0)
unnamed: U6.7 (A), U12.1 (CP1..3), U12.12 (Q0)
unnamed: U4.2, U6.1 (B), U12.9 (Q1)
unnamed: U6.6 (D), U12.11 (Q3)
unnamed: U7.7 (A), U13.1 (CP1..3), U13.12 (Q0)
unnamed: U7.2 (C), U13.8 (Q2)
unnamed: U7.1 (B), U13.9 (Q1)
unnamed: U7.6 (D), U13.11 (Q3), U14.14 (CP0)
unnamed: U8.7 (A), U14.1 (CP1..3), U14.12 (Q0)
unnamed: U8.1 (B), U14.3 (R0(2)), U14.9 (Q1)
unnamed: U8.6 (D), U14.11 (Q3)
unnamed: U9.7 (A), U15.1 (CP1..3), U15.12 (Q0)
unnamed: U9.2 (C), U15.2 (R0(1)), U15.8 (Q2), U16.2 (R0(1))
unnamed: U9.1 (B), U15.9 (Q1)
unnamed: U9.6 (D), U15.11 (Q3), U16.1 (CP1..3)
VCC: C1.1, C2.1, C3.1, C4.1, C5.1, C6.1, C7.1, C8.1, C9.1, C10.1, C11.1, C12.1, C13.1, C14.1, C15.1, C16.1, C17.1, D1.2 (A), D2.2 (A), D3.2 (A), D4.2 (A), P1.1, R1.2, R2.2, R3.2, R4.2, R5.2, U1.16 (VCC), U2.14 (VCC), U3.14 (VCC), U4.14 (VCC), U5.3 (LT), U5.5 (RBI), U5.16 (VCC), U6.3 (LT), U6.5 (RBI), U6.16 (VCC), U7.3 (LT), U7.5 (RBI), U7.16 (VCC), U8.3 (LT), U8.5 (RBI), U8.16 (VCC), U9.3 (LT), U9.5 (RBI), U9.16 (VCC), U10.3 (LT), U10.16 (VCC), U11.5 (VCC), U12.5 (VCC), U13.5 (VCC), U14.5 (VCC), U15.5 (VCC), U16.5 (VCC), U17.13 (DIG2_CA), U17.14 (DIG1_CA), U18.13 (DIG2_CA), U18.14 (DIG1_CA), U19.13 (DIG2_CA), U19.14 (DIG1_CA)

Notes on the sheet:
Seconds
Minutes
Power, Decoupling Capacitors
Hours Setup
Minutes Setup
Seconds Reset
Hours
2Hz Time Base

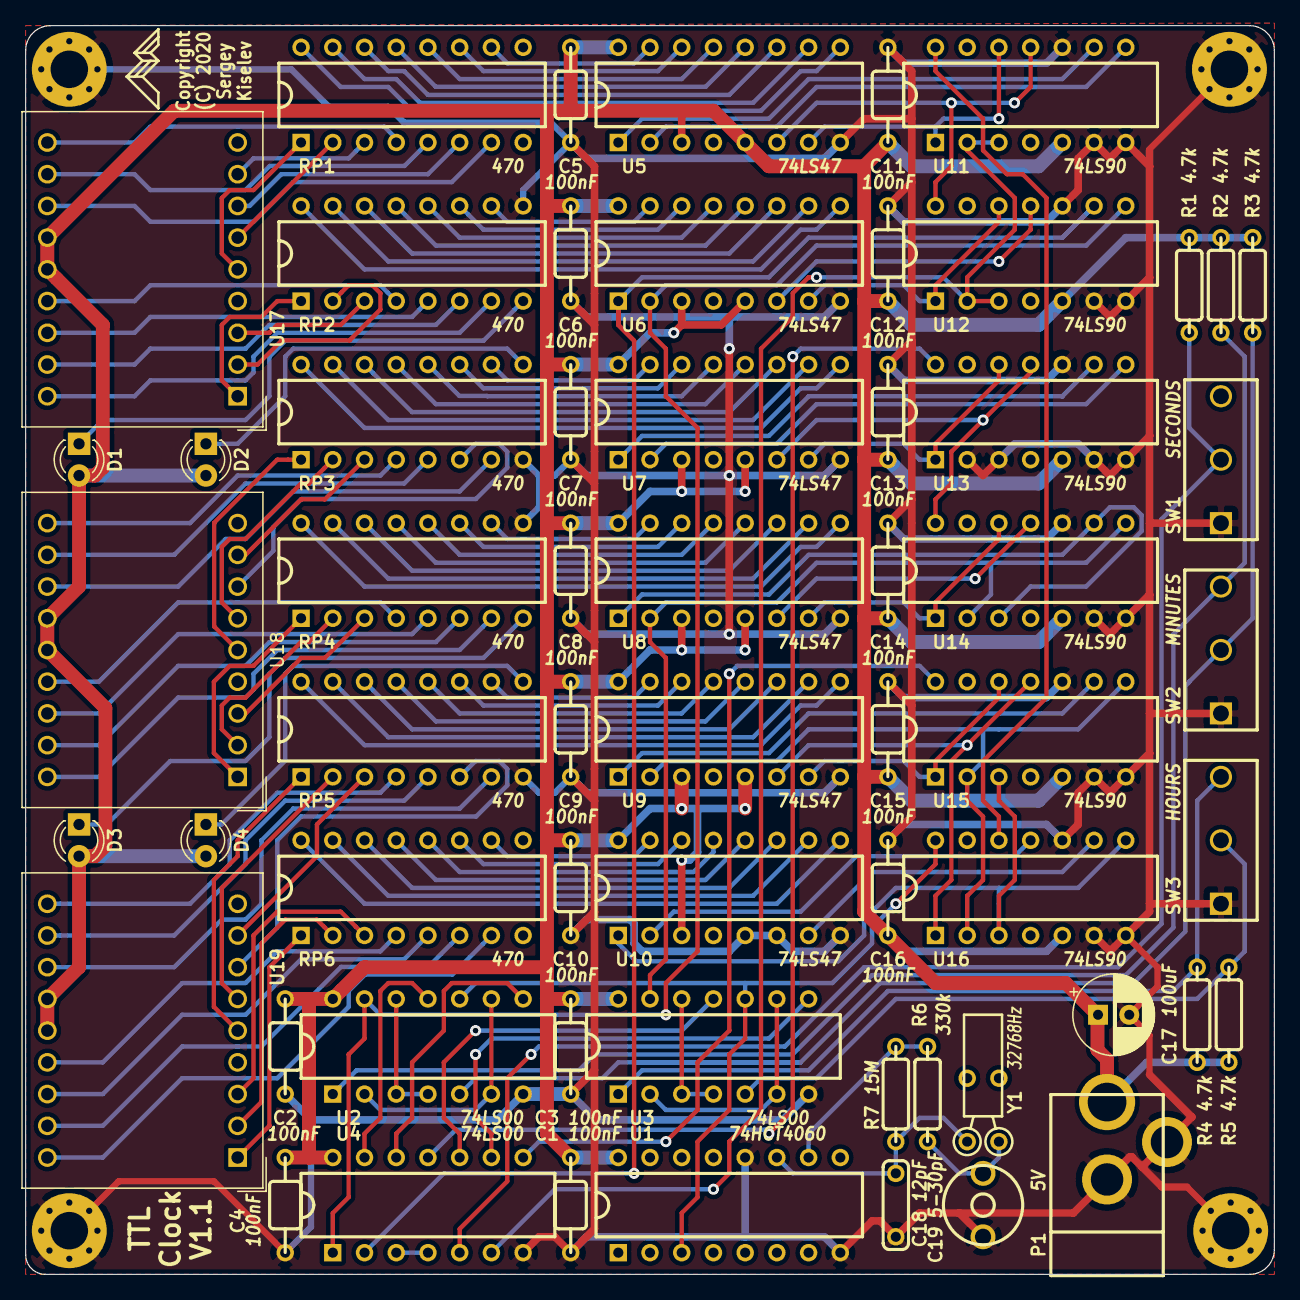
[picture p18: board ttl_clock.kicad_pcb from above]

Board: 2 copper layers, 100.0 x 100.0 mm, 64 parts (0 on the bottom side), 135 nets.

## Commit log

2020-12-03 Fix JPG extensions case
2020-12-04 Replace design files with version 1.1
    [led_clock.kicad_pcb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]
2020-12-04 README: Update parts for PCB version 1.1
2020-12-04 README: BOM Fixes
2020-12-08 Assembly_Instructions: Formatting
2020-12-09 Assembly_Instructions: More formatting
2020-12-11 Assembly_Instructions: Fix typos
2020-12-15 Update 3D printable stand for version 1.1
    [stand.scad, stand.stl, standforclock.stl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]

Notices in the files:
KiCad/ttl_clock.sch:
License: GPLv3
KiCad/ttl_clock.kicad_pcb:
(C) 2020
